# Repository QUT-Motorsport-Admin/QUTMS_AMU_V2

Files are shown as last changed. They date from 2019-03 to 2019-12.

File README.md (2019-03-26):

QUTMS_Banner
# QUTMS AMU V2
The Version 2 of the Accumulator Managment Unit. 

## Function
Monitoring and reporting the overall health of the accumulator unit which is derived from the cell temprature, charge balance and discharge characteristic received from individual BMS boards.

## Subsystem
* BMS

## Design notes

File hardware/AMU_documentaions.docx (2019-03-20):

This Document Contains all the necessary Information needed to understand the Design of the Current Accumulator Management System. However, this document will not cover everything about each of the component used to make the AMS. Thus, in case of need for any additional information, please see the table for the specific part to see its datasheet.

This section of the Schematic shows the connections from the batteries to the Accumulator Management System. MC78M05ACDT voltage regulator is to provide a 5V input to the ACPL-C87A Optocoupler. The specific usage of the optocoupler is meant to separate the High Voltage side from the low voltage side.

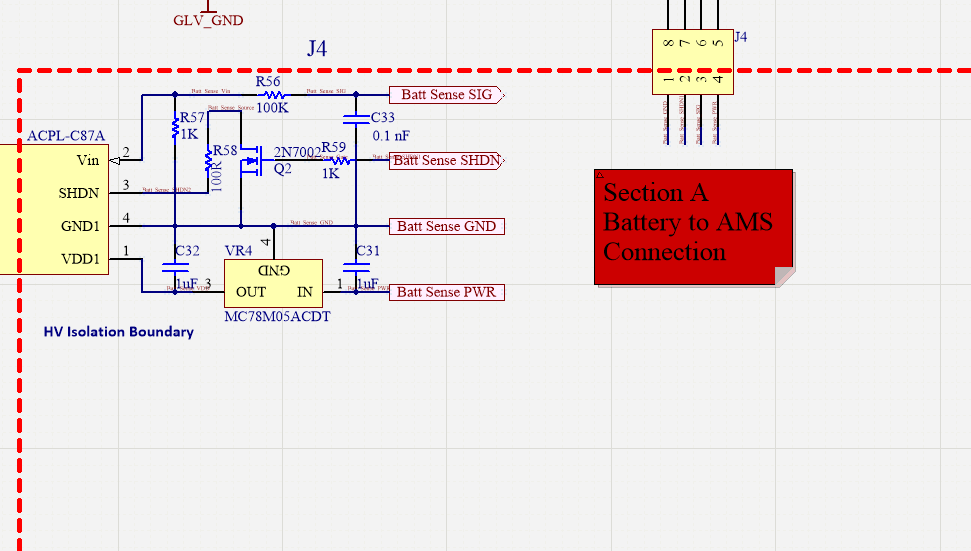
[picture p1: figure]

The set-up seeing above is based on the data-sheet recommendations as shown below in (fig 22):

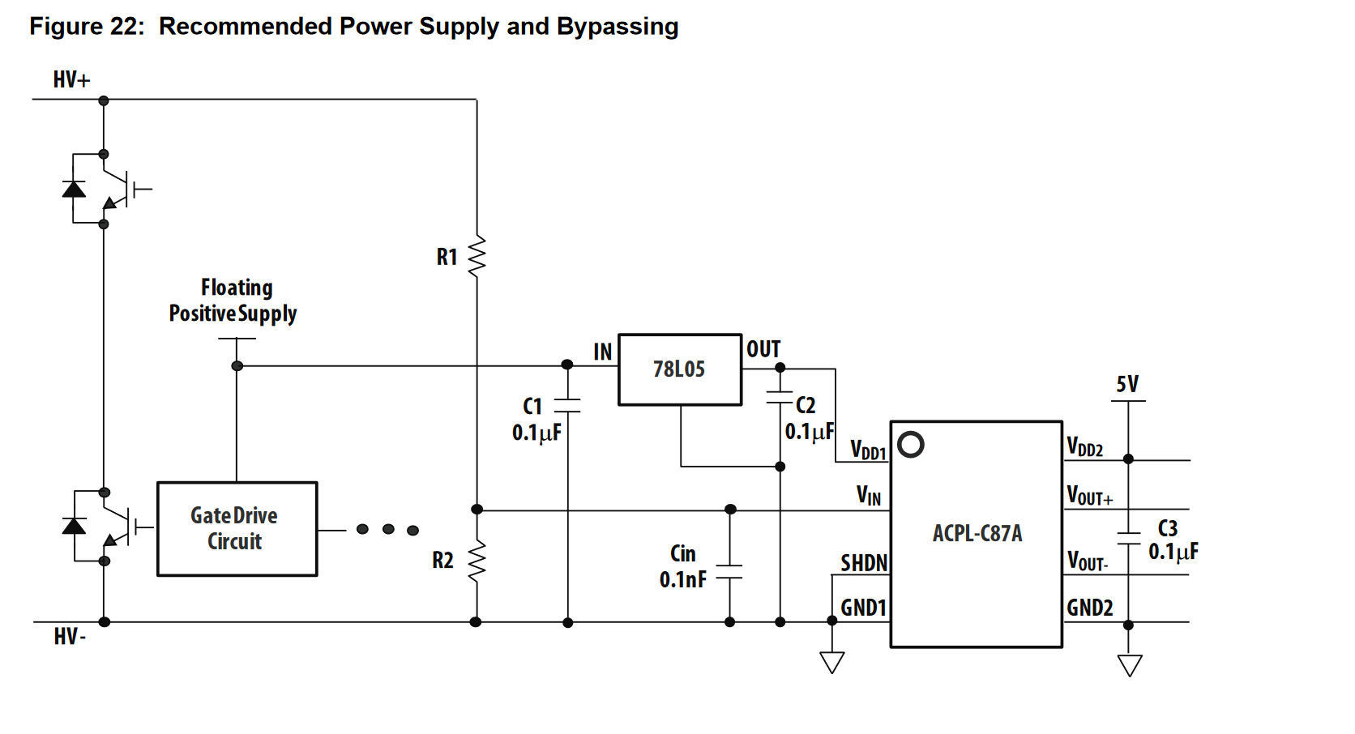
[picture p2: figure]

The Only difference between the two setups is that the AMS board will shut down if the SHDN pin has been triggered, this will only occur if the pin for battery SHDN sense a signal to drive the N-Channel MOSFET.

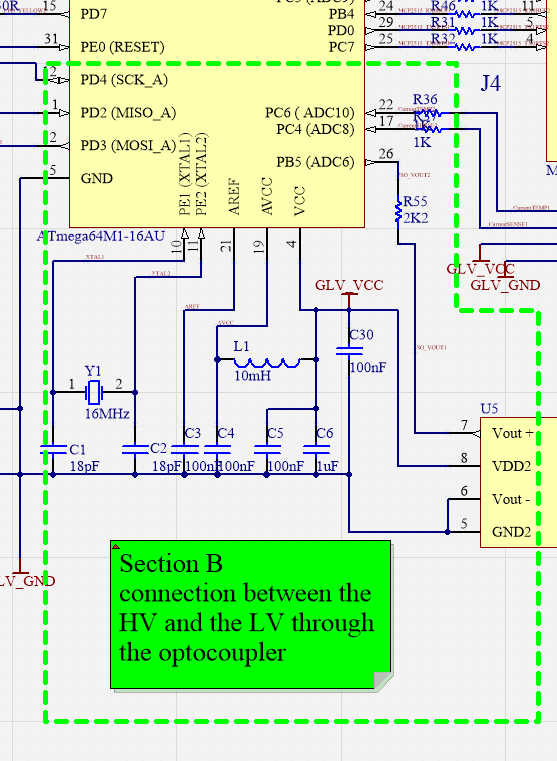
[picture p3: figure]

This section of the board features the added 16MHz crystal oscillator and its associated with it. The Section include as the optocoupler connection to the microcontroller.

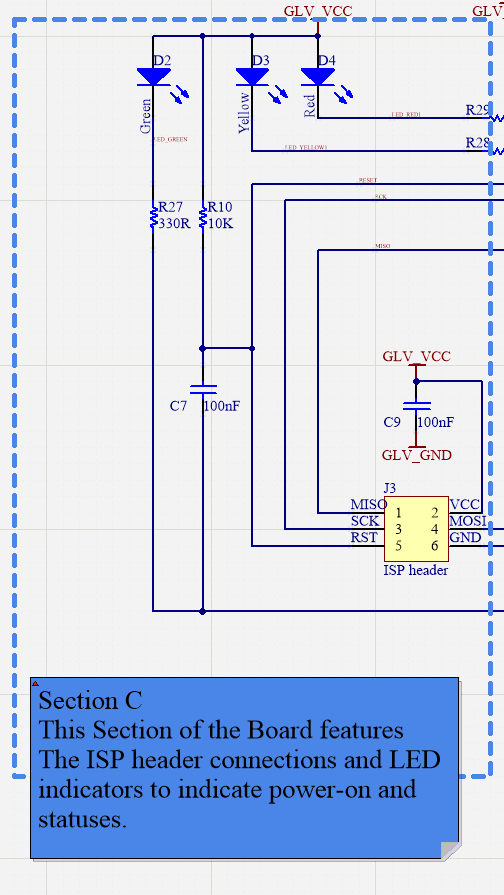
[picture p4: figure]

Section D

Linear Voltage regulator, to regulate the BMS LV input to 5 volts to suits each of U2, U3, U4 chips as well as all other section of the board that require 5V as input power.

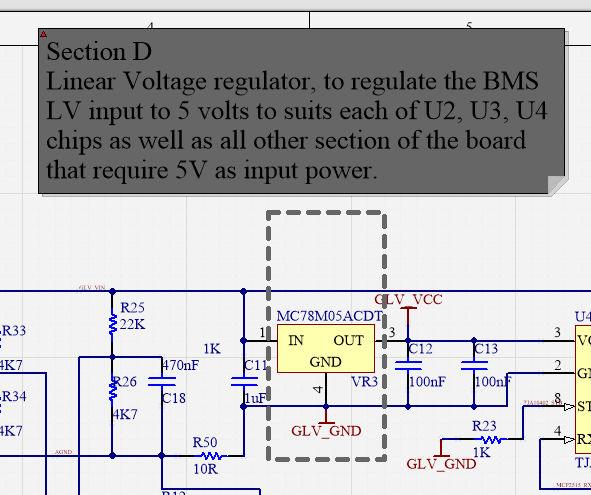
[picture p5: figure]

Section E

MCP2515-I/OS This chip is Microchip Technology’s MCP2515 is a stand-aloneController Area Network (CAN) controller that imple-ments the CAN specification, Version 2.0B. It is capableof transmitting and receiving both standard andextended data and remote frames. The MCP2515 hastwo acceptance masks and six acceptance filters thatare used to filter out unwanted messages, therebyreducing the host MCU’s overhead. The MCP2515interfaces with microcontrollers (MCUs) via an industrystandard Serial Peripheral Interface (SPI).

The chip requires an external XTAL crystal Oscillator, and since we have microcontroller running of 16 MHz clock, this external crystal clock has been determined to be 16MHz as well so systems are synchronised.

The MCP2515 require the following crystal set-up:

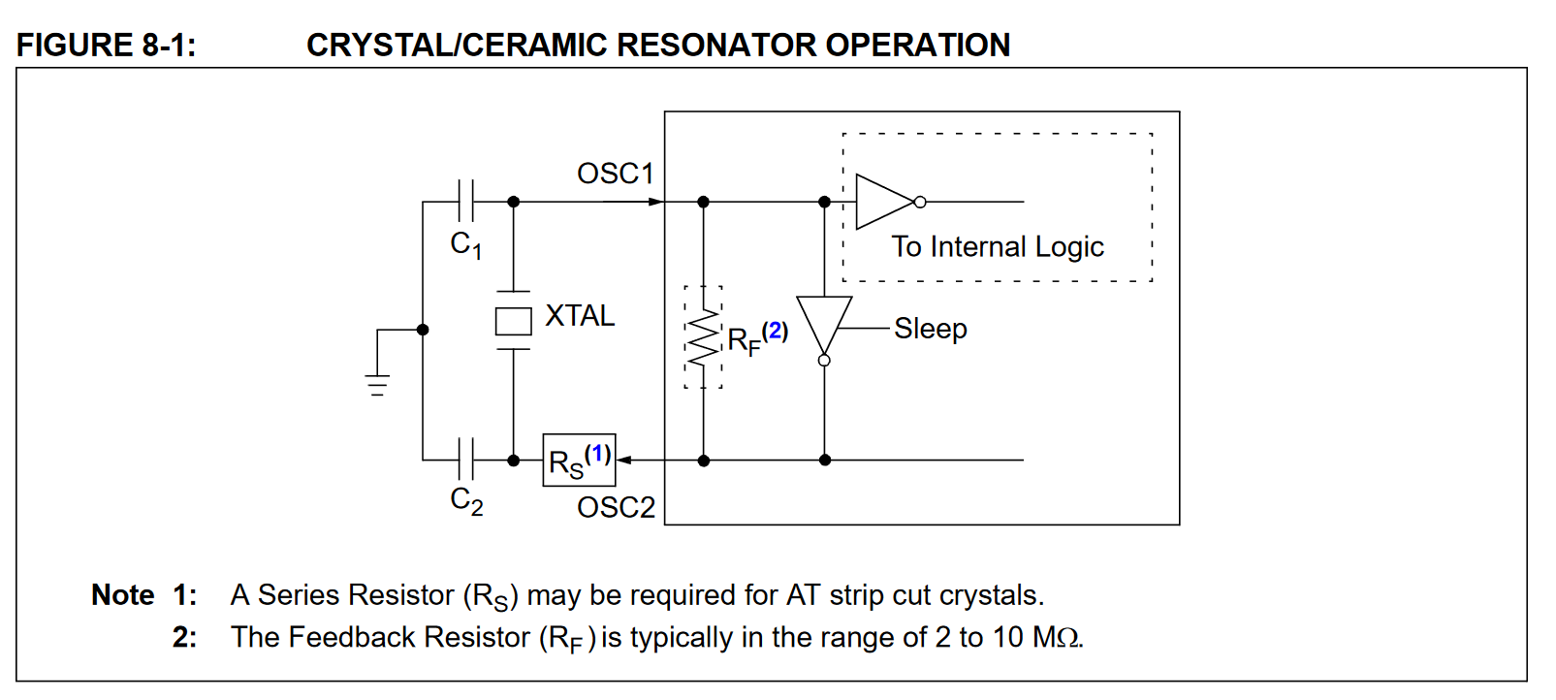
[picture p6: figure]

The Load capacitance of the selected oscillator is 12pF, and the CStary(varies from 2pF to 5pF depends how far is the oscillator from the chip) estimated to be 3pF if the component and crystal has been placed as close as possible to the chip:

Therefore, C1, C2 has been calculated to be 18pF.

18pF = 2*12 – 2*3

18pF = 24-6 pF

18pF = 18pF

Reference for this calculation is: https://blog.adafruit.com/2012/01/24/choosing-the-right-crystal-and-caps-for-your-design/

The chosen crystal is here: ECS-160-12-33Q-JEN-TR

Datasheet: https://au.mouser.com/datasheet/2/122/ECX-33Q-938166.pdf

Shift register:

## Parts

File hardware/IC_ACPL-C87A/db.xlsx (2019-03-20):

Library Ref | Library Path | Footprint Ref | Footprint Path | Footprint Ref 2 | Footprint Path 2 | Footprint Ref 3 | Footprint Path 3 | Footprint Ref 4 | Footprint Path 4 | Datasheet Path | Ambient Temperature Range High | Ambient Temperature Range Low | Automotive | Bandwidth | Capacitance | ComponentLink1Description | ComponentLink1URL | ComponentLink2Description | ComponentLink2URL | Datasheet Path | Description | Digikey Description | Digikey Part Number | Footprint Path | Footprint Path 2 | Footprint Path 3 | Footprint Path 4 | Footprint Ref | Footprint Ref 2 | Footprint Ref 3 | Footprint Ref 4 | Height | Inductance | Input Bias Current | Input Offset Voltage | Ipc Land Pattern Name | Lead Free | Library Path | Library Ref | Manufacturer | Max Dual Supply Voltage | Max Supply Voltage | Min Dual Supply Voltage | Min Supply Voltage | Mouser Description | Mouser Part Number | Nominal Supply Current | Number Of Channels | Output Current Per Channel | Package | Part Number | Price | Resistance | RoHS | Standoff Height | Supplier 1 | Supplier 2 | Supplier Part Number 1 | Supplier Part Number 2
ACPL-C87A-000E | parts/IC_Broadcom_ACPL-C87A-000E_eec.SchLib | Broadcom_SSO-8_MFG | parts/IC_Broadcom_ACPL-C87A-000E_eec_MFG.PcbLib | Broadcom_SSO-8_IPC_A | parts/IC_Broadcom_ACPL-C87A-000E_eec_IPC_A.PcbLib | Broadcom_SSO-8_IPC_B | parts/IC_Broadcom_ACPL-C87A-000E_eec_IPC_B.PcbLib | Broadcom_SSO-8_IPC_C | parts/IC_Broadcom_ACPL-C87A-000E_eec_IPC_C.PcbLib | datasheets/IC_Broadcom_ACPL-C87A-000E_eec.pdf | +105°C | -40°C | No | 100kHz | SKIP | Upverter | https://upverter.com/upn/revision/0986b70141264132/ | Datasheet | https://docs.broadcom.com/docs/AV02-3563EN | datasheets/IC_Broadcom_ACPL-C87A-000E_eec.pdf | IC OPAMP ISOLATION 100KHZ 8SO | IC OPAMP ISOLATION 100KHZ 8SO | 516-2577-5-ND | parts/IC_Broadcom_ACPL-C87A-000E_eec_MFG.PcbLib | parts/IC_Broadcom_ACPL-C87A-000E_eec_IPC_A.PcbLib | parts/IC_Broadcom_ACPL-C87A-000E_eec_IPC_B.PcbLib | parts/IC_Broadcom_ACPL-C87A-000E_eec_IPC_C.PcbLib | Broadcom_SSO-8_MFG | Broadcom_SSO-8_IPC_A | Broadcom_SSO-8_IPC_B | Broadcom_SSO-8_IPC_C | 3.607mm | SKIP | -0.0015uA | -0.3mV | SOIC127P1150X338-8 | Yes | parts/IC_Broadcom_ACPL-C87A-000E_eec.SchLib | ACPL-C87A-000E | Broadcom | 5.5V | 2V | 3V | 0V | Isolation Amplifier [Avago] ACPL-C87A-000E Isolation Amplifier | 630-ACPL-C87A-000E | 15-10500uA | 1 | 30mA | SSO-8 | ACPL-C87A-000E | SKIP | SKIP | TRUE | 0.1mm | Digi-Key | Mouser | 516-2577-5-ND | 630-ACPL-C87A-000E
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

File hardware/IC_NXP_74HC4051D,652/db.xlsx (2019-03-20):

Library Ref | Library Path | Footprint Ref | Footprint Path | Datasheet Path | Capacitance | ComponentLink1Description | ComponentLink1URL | ComponentLink2Description | ComponentLink2URL | Datasheet Path | Description | Digikey Description | Digikey Part Number | Footprint Path | Footprint Ref | Inductance | Lead Free | Library Path | Library Ref | Manufacturer | Mouser Part Number | Package | Part Number | Price | Resistance | RoHS | Supplier 1 | Supplier 2 | Supplier Part Number 1 | Supplier Part Number 2 | Temperature | Temperature Range High | Temperature Range Low | Value | Voltage | helpURL
74HC4051D,652 | parts/IC_NXP_74HC4051D,652_eec.SchLib | NXP_SOT109-1_0 | parts/IC_NXP_74HC4051D,652_eec_0.PcbLib | datasheets/IC_NXP_74HC4051D,652_eec.pdf | SKIP | Upverter | https://upverter.com/upn/revision/4a98814b0ae9cabd/ | Datasheet | https://assets.nexperia.com/documents/data-sheet/74HC_HCT4051.pdf | datasheets/IC_NXP_74HC4051D,652_eec.pdf | IC MUX/DEMUX 8X1 16SOIC | IC MUX/DEMUX 8X1 16SOIC | 1727-3789-ND | parts/IC_NXP_74HC4051D,652_eec_0.PcbLib | NXP_SOT109-1_0 | SKIP | yes | parts/IC_NXP_74HC4051D,652_eec.SchLib | 74HC4051D,652 | NXP | 771-74HC4051D | SOT109-1 | 74HC4051D,652 | SKIP | SKIP | TRUE | Digi-Key | Mouser | 1727-3789-ND | 771-74HC4051D | -40°C to +125°C | +125°C | -40°C | SKIP | SKIP | https://upverter.com/upn/revision/4a98814b0ae9cabd/

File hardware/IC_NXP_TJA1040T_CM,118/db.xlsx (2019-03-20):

Library Ref | Library Path | Footprint Ref | Footprint Path | Datasheet Path | Capacitance | ComponentLink1Description | ComponentLink1URL | ComponentLink2Description | ComponentLink2URL | Datasheet Path | Description | Digikey Description | Digikey Part Number | Footprint Path | Footprint Ref | Footprint Url | Height | Inductance | Interface | Lead Free | Library Path | Library Ref | Manufacturer | Max Junction Temp | Max Supply Voltage | Min Supply Voltage | Mouser Description | Mouser Part Number | Nominal Supply Current | Package | Part Number | Price | Resistance | RoHS | Standoff Height | Supplier 1 | Supplier 2 | Supplier Part Number 1 | Supplier Part Number 2 | Temperature | Temperature Range High | Temperature Range Low | Value | Verification Version | Voltage | helpURL
TJA1040T-CM,118 | parts/IC_NXP_TJA1040T-CM,118_eec.SchLib | NXP_SOT96-1_0 | parts/IC_NXP_TJA1040T-CM,118_eec_0.PcbLib | datasheets/IC_NXP_TJA1040T-CM,118_eec.pdf | SKIP | Upverter | https://upverter.com/upn/revision/853459073d63f8ee/ | Datasheet | https://www.nxp.com/docs/en/data-sheet/TJA1040.pdf | datasheets/IC_NXP_TJA1040T-CM,118_eec.pdf | IC TRANSCEIVER CAN 8SOIC | IC TRANSCEIVER CAN 8SOIC | 568-10289-1-ND | parts/IC_NXP_TJA1040T-CM,118_eec_0.PcbLib | NXP_SOT96-1_0 | https://www.nxp.com/docs/en/package-information/SOT96-1.pdf | 1.75mm | SKIP | CAN | yes | parts/IC_NXP_TJA1040T-CM,118_eec.SchLib | TJA1040T-CM,118 | NXP | +150°C | 5.25V | 4.75V | CAN Interface IC TJA1040T/CM/SO8/REEL 13" Q1/T1 | 771-TJA1040T/CM118 | 10uA | SOT96-1 | TJA1040T/CM,118 | SKIP | SKIP | TRUE | 0.1mm | Digi-Key | Mouser | 568-10289-1-ND | 771-TJA1040T/CM118 | -40°C to +150°C | +150°C | -40°C | SKIP | 0.0.0.1 | SKIP | https://upverter.com/upn/revision/853459073d63f8ee/

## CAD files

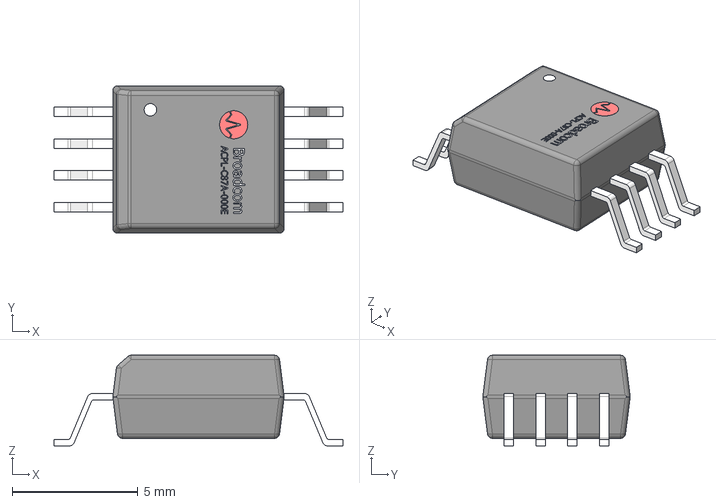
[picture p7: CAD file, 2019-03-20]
hardware/IC_ACPL-C87A/parts/IC_Broadcom_ACPL-C87A-000E_eec.STEP
11.5 x 5.85 x 3.61 mm

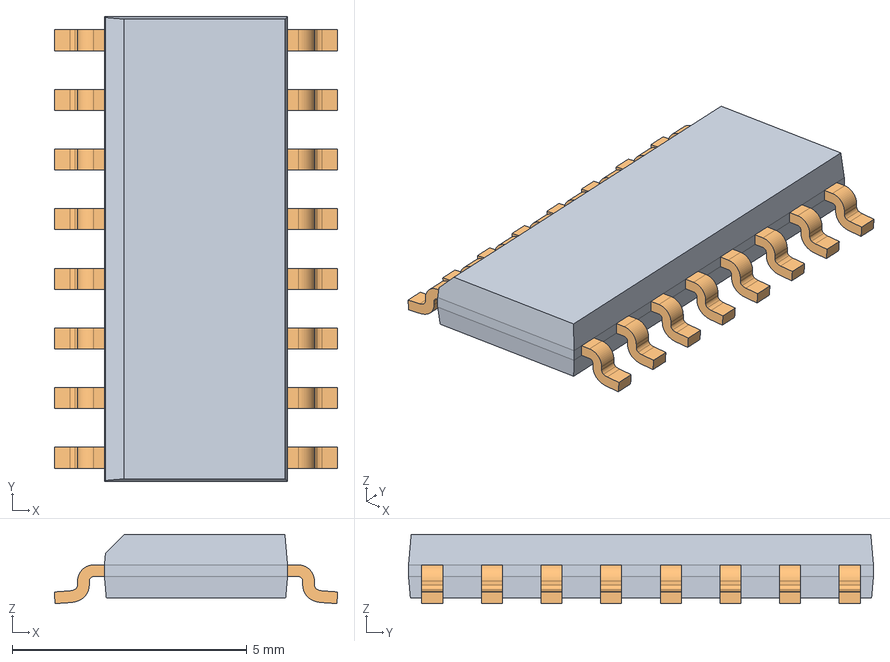
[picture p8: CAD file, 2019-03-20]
hardware/IC_NXP_74HC4051D,652/parts/IC_NXP_74HC4051D,652_eec.STEP
6.03 x 9.90 x 1.48 mm

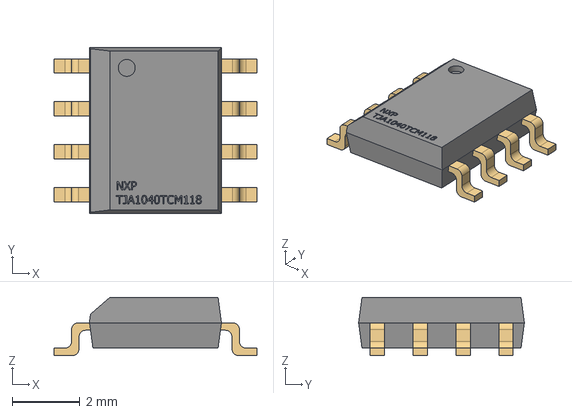
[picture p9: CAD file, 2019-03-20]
hardware/IC_NXP_TJA1040T_CM,118/parts/IC_NXP_TJA1040T-CM,118_eec.STEP
6.00 x 4.90 x 1.72 mm

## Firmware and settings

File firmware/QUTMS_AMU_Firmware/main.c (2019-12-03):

/*
 * QUTMS_HVBoard_Firmware.c
 *
 * Created: 18/09/2019 12:51:26 PM
 * Author : Zoe Goodward
 */

#define F_CPU 16000000UL /* CPU clock in Hertz */

#include <avr/io.h>
#include <util/delay.h>
#include <avr/interrupt.h>
#include <avr/pgmspace.h>

#include "input.h"
#include "UART.h"
#include "spi.h"
#include "adc.h"
#include "MCP2517.h"
#include "MCP2517_reg.h"

#define CHECK_BIT(var,pos) ((var) & (1<<(pos)))
uint8_t AMU_DATA[5] = {0};

/*============================================================================
Function:   AMU_init()
------------------------------------------------------------------------------
Purpose :   consolidates all the functions required for the initialisation of
			the AMU board
Input   :   none
Returns :   void
Notes   :
============================================================================*/
void AMU_init() 
{
	DDRB = 0b10110000; // MOSI and SCK and CAN_CS as output, SS output
	DDRA = 0b01010001; // LEDS
	// Set Pre-charge, Shutdown+ and Shutdown- as outputs
	DDRD = 0b00001110;
	
	CAN_CS_PORT |= (1 << CAN_CS); // CS high to turn off
	
	SHDN_NEG_OFF;
	SHDN_POS_OFF;
	PRE_CHARGE_OFF;
	
	//adc_init();
	//uart0_init(9600);
	spi_init(0,0); // 1,0
	MCP2517_init();
	sei(); // Enable interrupts
}

int main(void)
{
    AMU_init();
	
	uint8_t data[8] = {0};
	CAN_RECEIVE_ADDRESS receiveID;
	uint8_t numDataBytes;
	
    while(1) 
    {
		// Fan control pin is BMS alarm
		MCP2517_recieveMessage(&receiveID, &numDataBytes, data);
		if(receiveID == CAN_RECEIVE_ID_PDM >> 18) { // Use PDM CAN packet
			/* Byte 0 */
			if(CHECK_BIT(data[0], 6)) { // Shutdown -
				SHDN_NEG_ON;
			} else {
				SHDN_NEG_OFF;
			}
			if(CHECK_BIT(data[0], 7)) { // Shutdown +
				SHDN_POS_ON;
				LED_A_ON;
			} else {
				SHDN_POS_OFF;
				LED_A_OFF;
			}
			/* Byte 5 */
			if(CHECK_BIT(data[5], 0)) { // Pre-charge
				PRE_CHARGE_ON;
				LED_B_ON;
			} else {
				PRE_CHARGE_OFF;
				LED_B_OFF;
			}
			MCP2517_transmitMessage(CAN_SEND_ID_AMU, 5, AMU_DATA);
		} else {
			//
		}		
		receiveID = 0;		
    }
}

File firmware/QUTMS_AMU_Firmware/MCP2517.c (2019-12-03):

/*****************************************************************************
* @file    firmware/QUTMS_HVBoard_Firmware/MCP2517.c
* @author  Zoe Goodward
* @version V1.0.0
* @date
* @brief
*****************************************************************************/
// 5:39PM 21/11/2019

#define F_CPU 16000000UL /* CPU clock in Hertz */

#include <util/delay.h>

#include <avr/io.h>
#include <avr/interrupt.h>
#include <avr/pgmspace.h>
#include <stdbool.h>

#include "input.h"
#include "UART.h"
#include "spi.h"
#include "MCP2517.h"
#include "MCP2517_reg.h"
#include "MCP2517_defines.h"


// *****************************************************************************
// Helper Functions
// *****************************************************************************
inline void enterWordInBufferAtIndex (const uint32_t value, uint8_t buff[], const uint8_t index) {
	buff[index + 0] = (uint8_t) value;
	buff[index + 1] = (uint8_t) (value >> 8);
	buff[index + 2] = (uint8_t) (value >> 16);
	buff[index + 3] = (uint8_t) (value >> 24);
}

inline uint32_t wordFromBufferAtIndex (uint8_t buff[], const uint8_t index) {
	uint32_t result = (uint32_t) buff[index + 0];
	result |= ((uint32_t) buff[index + 1]) << 8;
	result |= ((uint32_t) buff[index + 2]) << 16;
	result |= ((uint32_t) buff[index + 3]) << 24;
	return result;
}


// *****************************************************************************
// SPI Write Functions
// *****************************************************************************
inline void MCP2517_writeReg8(const uint16_t regAddr, const uint8_t value) {
	uint8_t buff[3] = {0};

	buff[0] = (uint8_t) ((MCP2517_INSTRUCTION_WRITE << 4) + ((regAddr >> 8) & 0xF));
	buff[1] = (uint8_t) (regAddr & 0xFF);
	buff[2] = value;
	
	MCP2517_assertCS();
	spi_transfer_buffer(buff, 3);
	MCP2517_deassertCS();
}

inline void MCP2517_writeReg32(const uint16_t regAddr, const uint32_t value) {
	uint8_t buff[6] = {0};
	
	buff[0] = (uint8_t) ((MCP2517_INSTRUCTION_WRITE << 4) + ((regAddr >> 8) & 0xF));
	buff[1] = (uint8_t) (regAddr & 0xFF);
	
	enterWordInBufferAtIndex(value, buff, 2);
	
	MCP2517_assertCS();
	spi_transfer_buffer(buff, 6);
	MCP2517_deassertCS();
}


// *****************************************************************************
// SPI Read Functions
// *****************************************************************************
inline uint8_t MCP2517_readReg8(const uint16_t regAddr) {
	uint8_t buff[3] = {0};

	buff[0] = (uint8_t) ((MCP2517_INSTRUCTION_READ << 4) + ((regAddr >> 8) & 0xF));
	buff[1] = (uint8_t) (regAddr & 0xFF);
	buff[2] = 0x00;
	
	MCP2517_assertCS();
	spi_transfer_buffer(buff, 3);
	MCP2517_deassertCS();
	
	return buff[2];
}

// change to uint8_t
inline uint32_t MCP2517_readReg32(const uint16_t regAddr) {
	uint8_t buff[6] = {0};

	buff[0] = (uint8_t) ((MCP2517_INSTRUCTION_READ << 4) + ((regAddr >> 8) & 0xF));
	buff[1] = (uint8_t) (regAddr & 0xFF);
	buff[2] = 0x00;

	MCP2517_assertCS();
	spi_transfer_buffer(buff, 6);
	MCP2517_deassertCS();

	const uint32_t result = wordFromBufferAtIndex(buff, 2); // change to uint8_t

	return result;
}

// *****************************************************************************
// Assert the MCP2517 CS pin
// *****************************************************************************
void MCP2517_assertCS() {
	CAN_CS_PORT &= ~(1 << CAN_CS);
}

void MCP2517_deassertCS() {
	CAN_CS_PORT |= (1 << CAN_CS);
}


// *****************************************************************************
// MCP2517 Configuration Functions
// *****************************************************************************
// Software reset
void MCP2517_reset() {
	uint8_t buff[2] = {0};
	
	buff[0] = (uint8_t) ((MCP2517_INSTRUCTION_WRITE << 4) + ((MCP2517_REG_ADDR_C1CON >> 8) & 0xF));
	buff[1] = (uint8_t) (MCP2517_REG_ADDR_C1CON & 0xFF);
	
	MCP2517_assertCS();
	spi_transfer_buffer(buff, 2);
	MCP2517_deassertCS();
}

// Set operation mode
void MCP2517_setMode(MCP2517_OPERATION_MODE opMode) {
	// Set mode and abort all transactions
	MCP2517_writeReg8(MCP2517_REG_ADDR_C1CON + 3, opMode | (1 << 3));
}

// Read current operation mode
uint8_t MCP2517_getMode() {
	return (MCP2517_readReg8(MCP2517_REG_ADDR_C1CON + 2) >> 5) & 0x07;
}

// Test that RAM is reading and writing correctly - !!!!
void MCP2517_testRAM() {
	for (uint32_t i = 1 ; i != 0; i <<= 1) {
		MCP2517_writeReg32(MCP2517_RAM_ADDR_START, i);
		const uint32_t readBackValue = MCP2517_readReg32(0x400);
		if (readBackValue != i) {
			uart0_transmit(MCP2517_RAM_ERROR); // Error code
		}
	}
}
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

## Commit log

2019-03-20 Unfinished AMU, PCB needs to made routed
    [1N4004_DO_214AC.PcbLib, AMU_Version_3.PrjPcb, AMU_Version_3.SchDoc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]
2019-09-11 add fan controller files (not complete)
    [AccumulatorFanController.PcbDoc, AccumulatorFanController.PrjPcb, AccumulatorFanController.SchDoc]
2019-12-03 Organise files, add basic AMU code for receiving CANBUS message and switching on and off the Shutdown + and - and precharge circuitry
    [1N4004_DO_214AC.PcbLib, AMU_Version_3.PrjPcb, AMU_Version_3.SchDoc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]
